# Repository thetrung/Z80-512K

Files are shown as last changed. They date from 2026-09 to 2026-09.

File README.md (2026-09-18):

# Z80-512K 
Z80 system with 512K SRAM/EEPROM & Expansion Bus.

### Note
This one start as independent Z80 system, target at 8Mhz clock & put any I/O into expansion bus instead.

### 3D Preview 
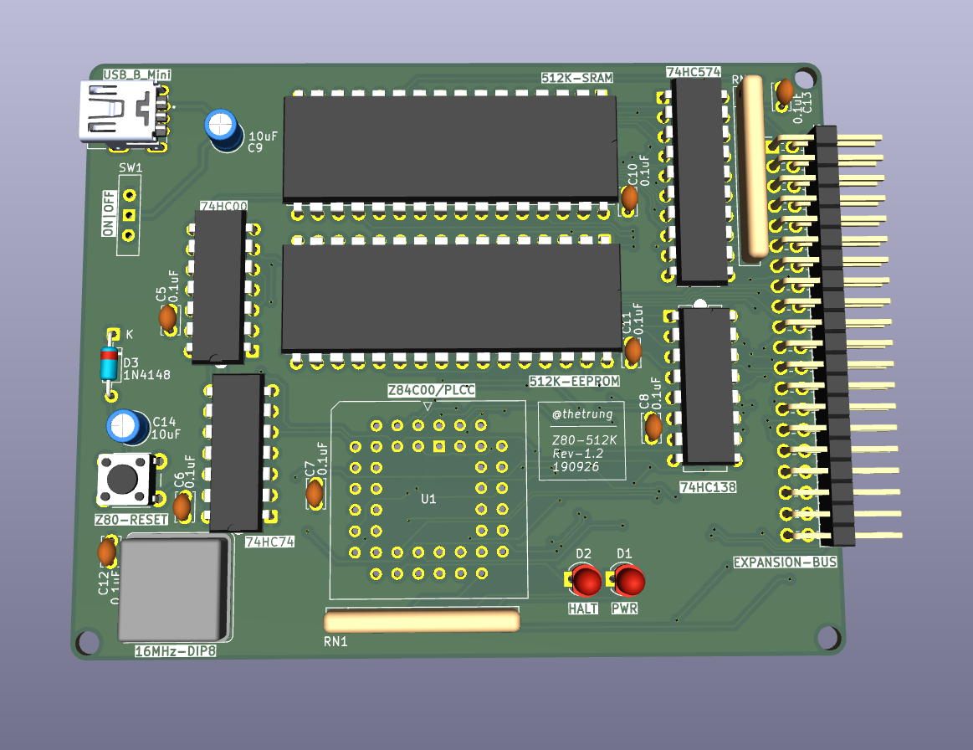
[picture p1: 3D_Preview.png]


### Placement (SilkScreen)
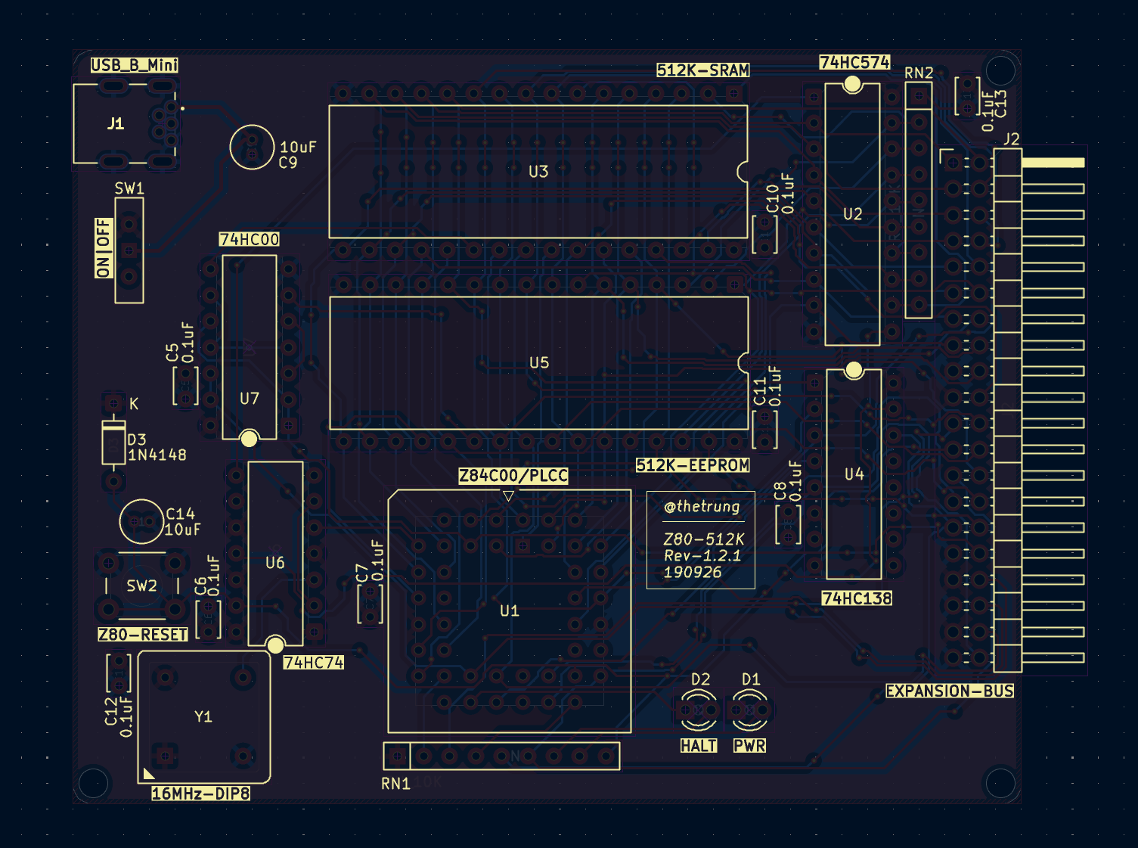
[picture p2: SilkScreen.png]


### Schematic 
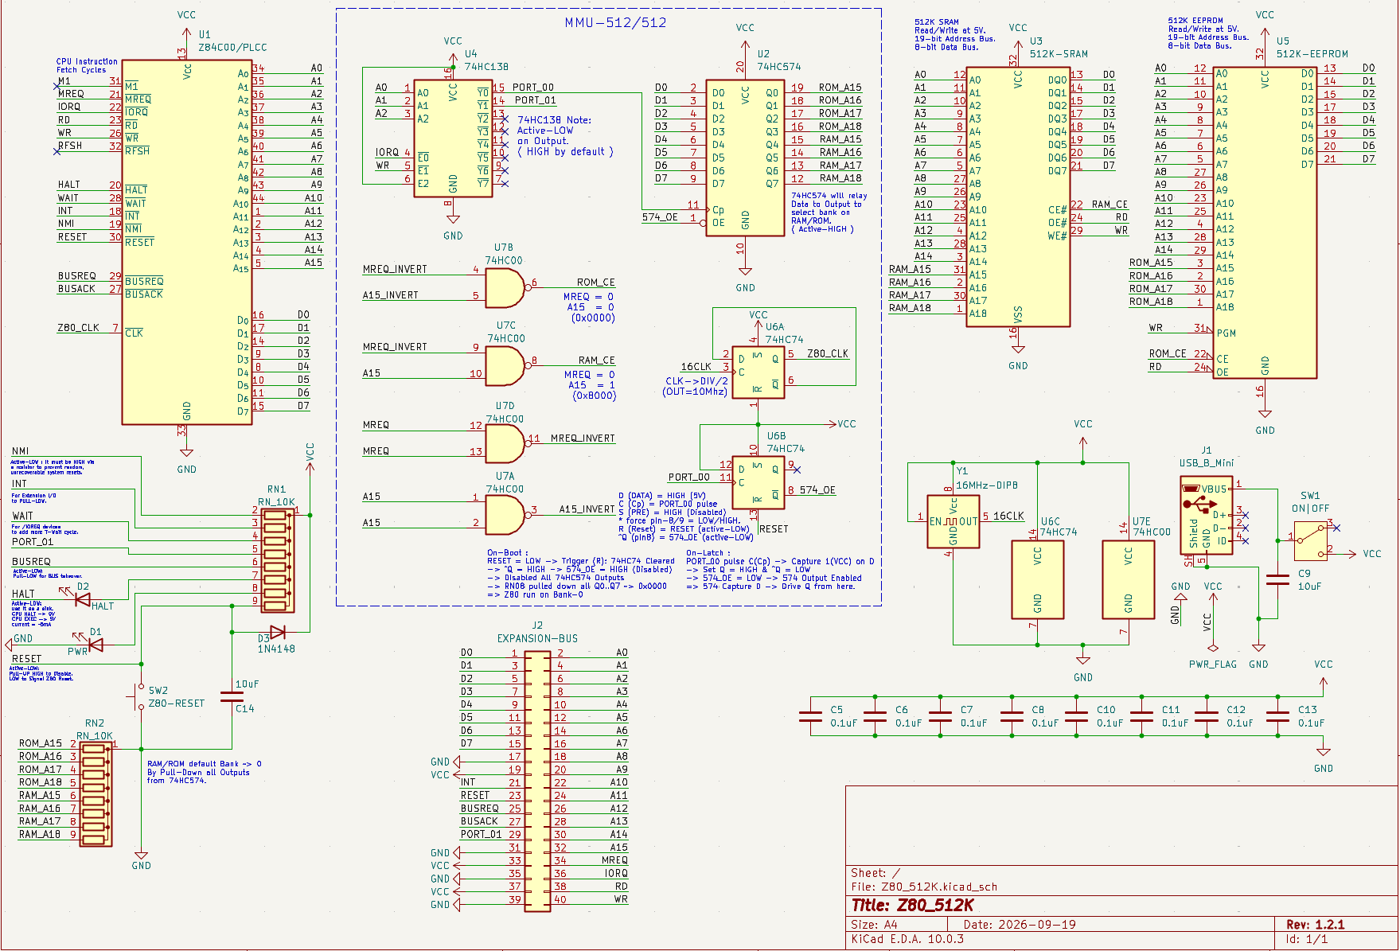
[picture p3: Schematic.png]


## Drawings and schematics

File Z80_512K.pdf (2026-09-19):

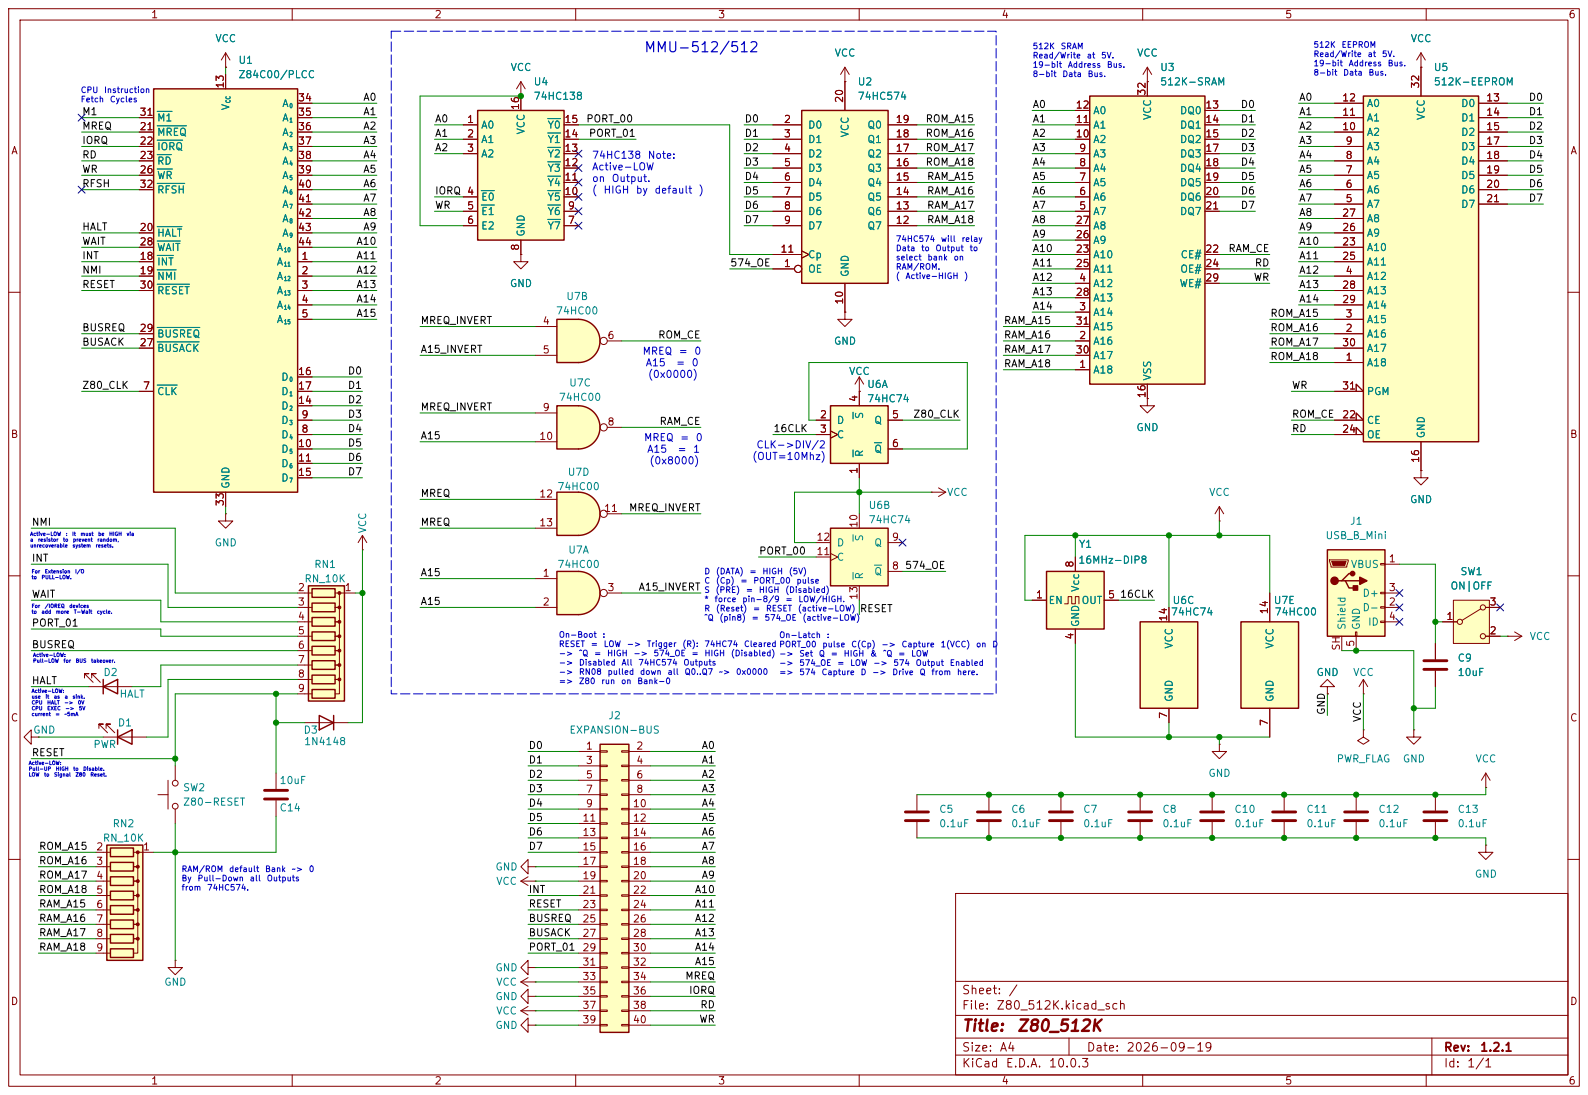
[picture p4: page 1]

VCC
512K SRAM Read/Write at 5V. 19-bit Address Bus. 8-bit Data Bus. U1

INT 18 NMI 19 HALT 20 MREQ 21

512K EEPROM
Read/Write at 5V. 19-bit Address Bus. 8-bit Data Bus.
512K-SRAM VSS 16 VCC 32
GNDVSS 16 VCC 32

Z84C00/PLCC

Active-LOW: Pull-LOW for BUS takeover. For Extension I/O
to PULL-LOW. For /IOREQ devices

Active-LOW: use it as a sink. CPU HALT -> 0V CPU EXEC -> 5V

Active-LOW: Pull-UP HIGH to Disable. LOW to Signal Z80 Reset.

Size: A4 | Rev: 1.2.1
KiCad E.D.A. 10.0.3 | Id: 1/1

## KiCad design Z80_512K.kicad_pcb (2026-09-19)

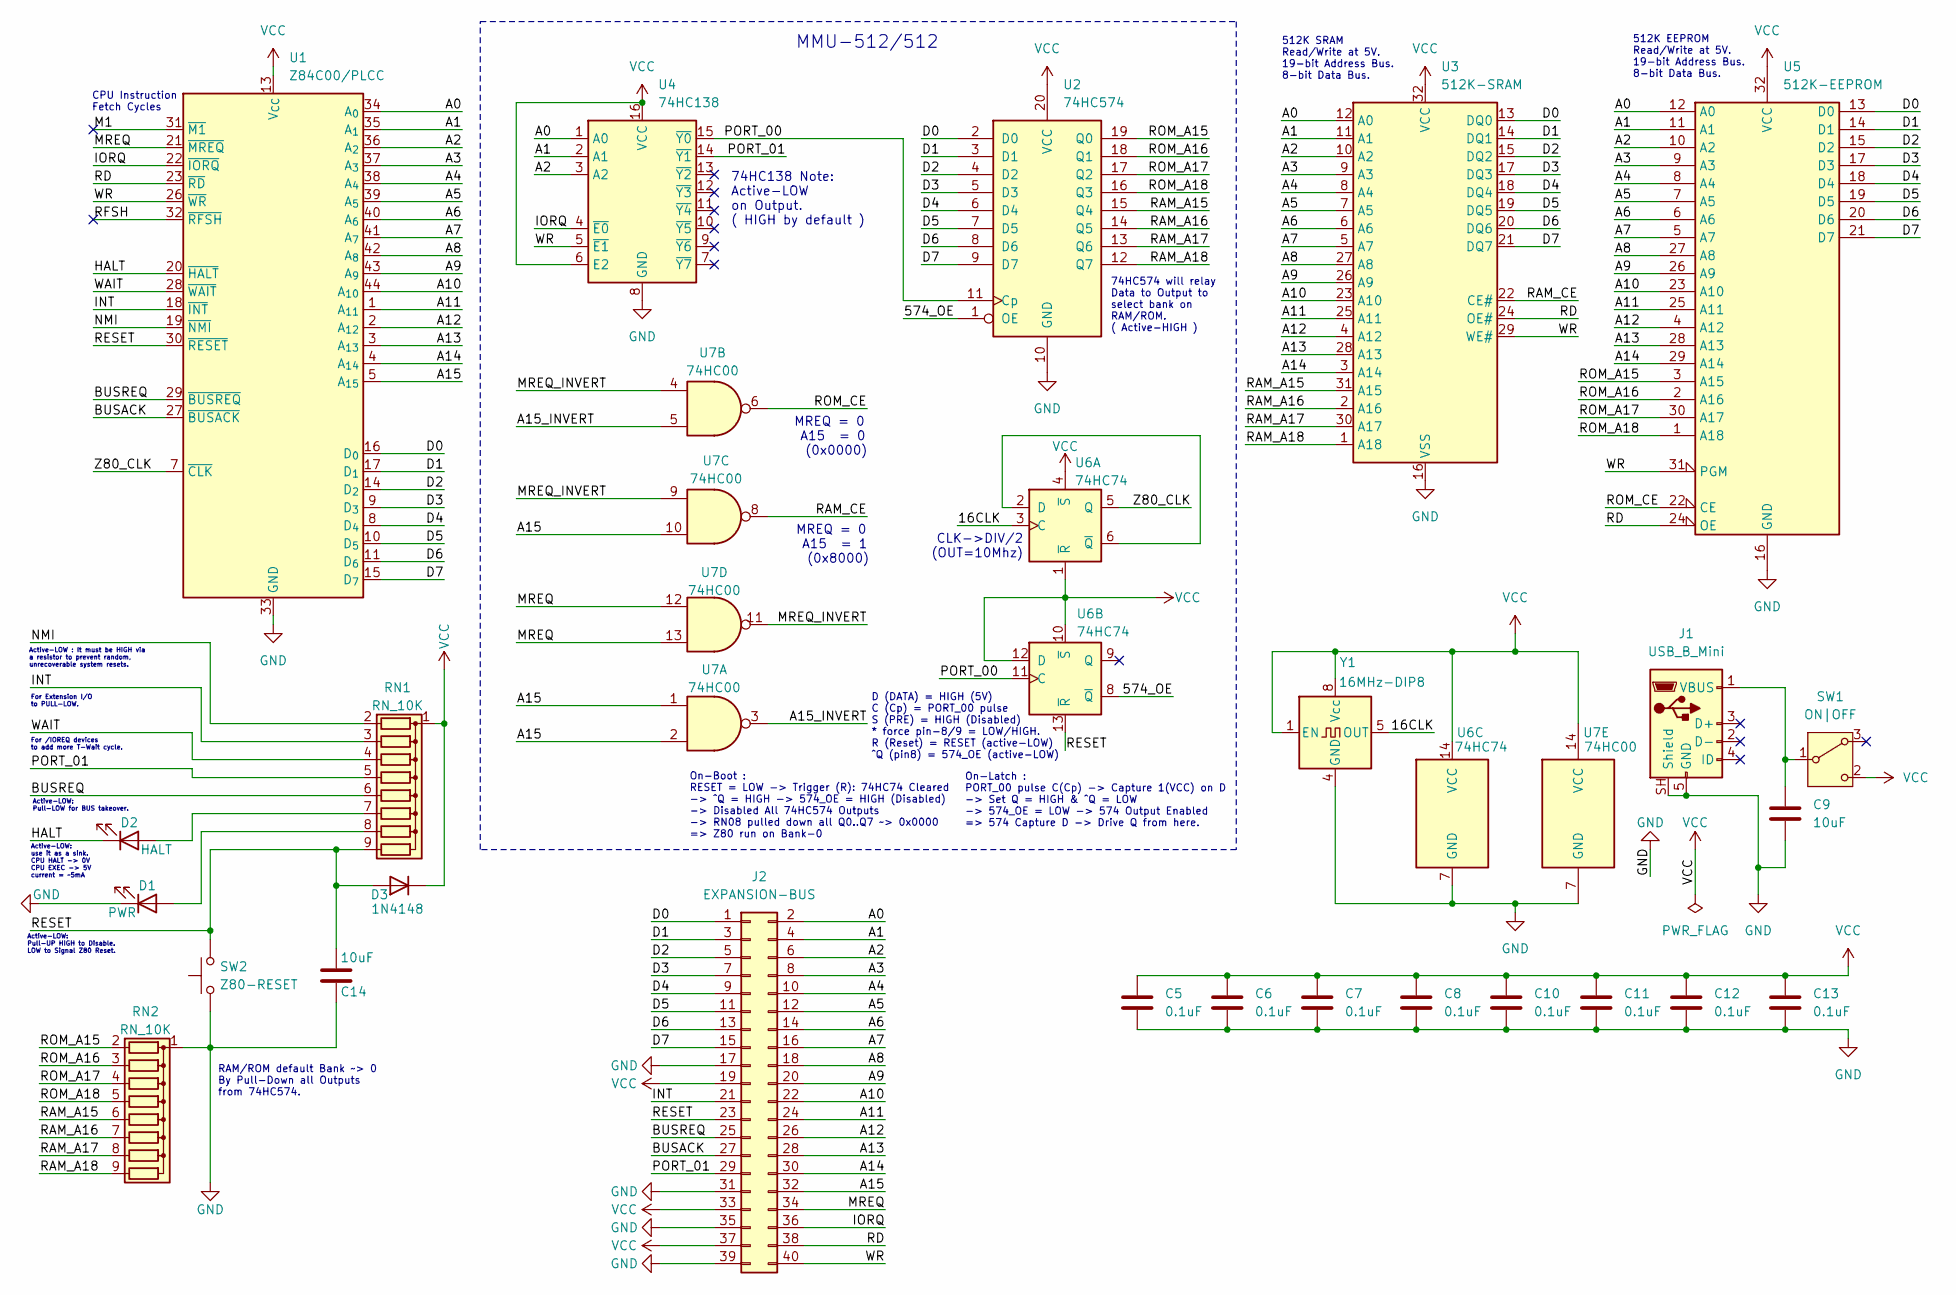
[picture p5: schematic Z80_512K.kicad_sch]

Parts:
C5, C6, C7, C8, C10, C11, C12, C13: 0.1uF; C_Disc_D3.4mm_W2.1mm_P2.50mm
C9, C14: 10uF; C_Radial_D4.0mm_H5.0mm_P1.50mm
D1: PWR; LED_D3.0mm
D2: HALT; LED_D3.0mm
D3: 1N4148; D_DO-35_SOD27_P7.62mm_Horizontal
J1: USB_B_Mini; USB_MINI_B_90_Angled
J2: EXPANSION-BUS; PinHeader_2x20_P2.54mm_Horizontal
RN1, RN2: RN_10K; R_Array_SIP9
SW1: ON|OFF; SW_Slide-03_Wuerth-WS-SLTV_10x2.5x6.4_P2.54mm
SW2: Z80-RESET; SW_PUSH_6mm
U1: Z84C00/PLCC; PLCC-44_THT-Socket
U2: 74HC574; DIP-20_W7.62mm
U3: 512K-SRAM; DIP-32_W15.24mm
U4: 74HC138; DIP-16_W7.62mm
U5: 512K-EEPROM; DIP-32_W15.24mm
U6: 74HC74; DIP-14_W7.62mm
U7: 74HC00; DIP-14_W7.62mm
Y1: 16MHz-DIP8; Oscillator_DIP-8

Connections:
/16CLK: U6.3 (C), Y1.5 (OUT)
/574_OE: U2.1 (OE), U6.8 (~Q)
/A0: J2.2, U1.34 (A_{0}), U3.12 (A0), U4.1 (A0), U5.12 (A0)
/A1: J2.4, U1.35 (A_{1}), U3.11 (A1), U4.2 (A1), U5.11 (A1)
/A2: J2.6, U1.36 (A_{2}), U3.10 (A2), U4.3 (A2), U5.10 (A2)
/A3: J2.8, U1.37 (A_{3}), U3.9 (A3), U5.9 (A3)
/A4: J2.10, U1.38 (A_{4}), U3.8 (A4), U5.8 (A4)
/A5: J2.12, U1.39 (A_{5}), U3.7 (A5), U5.7 (A5)
/A6: J2.14, U1.40 (A_{6}), U3.6 (A6), U5.6 (A6)
/A7: J2.16, U1.41 (A_{7}), U3.5 (A7), U5.5 (A7)
/A8: J2.18, U1.42 (A_{8}), U3.27 (A8), U5.27 (A8)
/A9: J2.20, U1.43 (A_{9}), U3.26 (A9), U5.26 (A9)
/A10: J2.22, U1.44 (A_{10}), U3.23 (A10), U5.23 (A10)
/A11: J2.24, U1.1 (A_{11}), U3.25 (A11), U5.25 (A11)
/A12: J2.26, U1.2 (A_{12}), U3.4 (A12), U5.4 (A12)
/A13: J2.28, U1.3 (A_{13}), U3.28 (A13), U5.28 (A13)
/A14: J2.30, U1.4 (A_{14}), U3.3 (A14), U5.29 (A14)
/A15: J2.32, U1.5 (A_{15}), U7.1, U7.2, U7.10
/A15_INVERT: U7.3, U7.5
/BUSACK: J2.27, U1.27 (~BUSACK)
/BUSREQ: J2.25, RN1.6 (R5), U1.29 (~BUSREQ)
/D0: J2.1, U1.16 (D_{0}), U2.2 (D0), U3.13 (DQ0), U5.13 (D0)
/D1: J2.3, U1.17 (D_{1}), U2.3 (D1), U3.14 (DQ1), U5.14 (D1)
/D2: J2.5, U1.14 (D_{2}), U2.4 (D2), U3.15 (DQ2), U5.15 (D2)
/D3: J2.7, U1.9 (D_{3}), U2.5 (D3), U3.17 (DQ3), U5.17 (D3)
/D4: J2.9, U1.8 (D_{4}), U2.6 (D4), U3.18 (DQ4), U5.18 (D4)
/D5: J2.11, U1.10 (D_{5}), U2.7 (D5), U3.19 (DQ5), U5.19 (D5)
/D6: J2.13, U1.11 (D_{6}), U2.8 (D6), U3.20 (DQ6), U5.20 (D6)
/D7: J2.15, U1.15 (D_{7}), U2.9 (D7), U3.21 (DQ7), U5.21 (D7)
/HALT: D2.1 (K), U1.20 (~HALT)
/INT: J2.21, RN1.3 (R2), U1.18 (~INT)
/IORQ: J2.36, U1.22 (~IORQ), U4.4 (~E0)
/M1: U1.31 (~M1)
/MREQ: J2.34, U1.21 (~MREQ), U7.12, U7.13
/MREQ_INVERT: U7.4, U7.9, U7.11
/NMI: RN1.2 (R1), U1.19 (~NMI)
/PORT_00: U2.11 (Cp), U4.15 (~Y0), U6.11 (C)
/PORT_01: J2.29, RN1.5 (R4), U4.14 (~Y1)
/RAM_A15: RN2.6 (R5), U2.15 (Q4), U3.31 (A15)
/RAM_A16: RN2.7 (R6), U2.14 (Q5), U3.2 (A16)
/RAM_A17: RN2.8 (R7), U2.13 (Q6), U3.30 (A17)
/RAM_A18: RN2.9 (R8), U2.12 (Q7), U3.1 (A18)
/RAM_CE: U3.22 (CE#), U7.8
/RD: J2.38, U1.23 (~RD), U3.24 (OE#), U5.24 (OE)
/RESET: C14.1, D3.2 (A), J2.23, RN1.9 (R8), SW2.2, U1.30 (~RESET), U6.13 (~R)
/RFSH: U1.32 (~RFSH)
/ROM_A15: RN2.2 (R1), U2.19 (Q0), U5.3 (A15)
/ROM_A16: RN2.3 (R2), U2.18 (Q1), U5.2 (A16)
/ROM_A17: RN2.4 (R3), U2.17 (Q2), U5.30 (A17)
/ROM_A18: RN2.5 (R4), U2.16 (Q3), U5.1 (A18)
/ROM_CE: U5.22 (CE), U7.6
/WAIT: RN1.4 (R3), U1.28 (~WAIT)
/WR: J2.40, U1.26 (~WR), U3.29 (WE#), U4.5 (~E1), U5.31 (PGM)
/Z80_CLK: U1.7 (~CLK), U6.5 (Q)
GND: C5.1, C6.1, C7.1, C8.1, C9.1, C10.1, C11.1, C12.1, C13.1, C14.2, D1.1 (K), J1.5 (GND), J1.SH (Shield), J2.17, J2.31, J2.35, J2.39, RN2.1 (common), SW2.1, U1.33 (GND), U2.10 (GND), U3.16 (VSS), U4.8 (GND), U5.16 (GND), U6.7 (GND), U7.7 (GND), Y1.4 (GND)
unnamed: D1.2 (A), RN1.8 (R7)
unnamed: D2.2 (A), RN1.7 (R6)
unnamed: C9.2, J1.1 (VBUS), SW1.1 (B)
unnamed: U6.2 (D), U6.6 (~Q)
VCC: C5.2, C6.2, C7.2, C8.2, C10.2, C11.2, C12.2, C13.2, D3.1 (K), J2.19, J2.33, J2.37, RN1.1 (common), SW1.2 (C), U1.13 (V_{CC}), U2.20 (VCC), U3.32 (VCC), U4.6 (E2), U4.16 (VCC), U5.32 (VCC), U6.1 (~R), U6.4 (~S), U6.10 (~S), U6.12 (D), U6.14 (VCC), U7.14 (VCC), Y1.1 (EN), Y1.8 (Vcc)

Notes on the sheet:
MREQ = 0 A15 = 0 (0x0000)
RAM/ROM default Bank ~> 0 By Pull-Down all Outputs from 74HC574.
For /IOREQ devices to add more T-Wait cycle.
512K SRAM Read/Write at 5V. 19-bit Address Bus. 8-bit Data Bus.
Active-LOW: use it as a sink. CPU HALT -> 0V CPU EXEC -> 5V current = ~5mA
CLK->DIV/2 (OUT=10Mhz)
For Extension I/O to PULL-LOW.
74HC138 Note: Active-LOW on Output. ( HIGH by default )
D (DATA) = HIGH (5V) C (Cp) = PORT_00 pulse S (PRE) = HIGH (Disabled) * force pin-8/9 = LOW/HIGH. R (Reset) = RESET (active-LOW) ^Q (pin8) = 574_OE (active-LOW)
512K EEPROM Read/Write at 5V. 19-bit Address Bus. 8-bit Data Bus.
On-Boot : RESET = LOW -> Trigger (R): 74HC74 Cleared -> ^Q = HIGH -> 574_OE = HIGH (Disabled) -> Disabled All 74HC574 Outputs -> RN08 pulled down all Q0..Q7 ~> 0x0000 => Z80 run on Bank-0
Active-LOW : It must be HIGH via a resistor to prevent random, unrecoverable system resets.
Active-LOW: Pull-UP HIGH to Disable. LOW to Signal Z80 Reset.
On-Latch : PORT_00 pulse C(Cp) -> Capture 1(VCC) on D -> Set Q = HIGH & ^Q = LOW -> 574_OE = LOW -> 574 Output Enabled => 574 Capture D -> Drive Q from here.
74HC574 will relay Data to Output to select bank on RAM/ROM. ( Active-HIGH )
CPU Instruction Fetch Cycles
Active-LOW: Pull-LOW for BUS takeover.
MREQ = 0 A15 = 1 (0x8000)
MMU-512/512

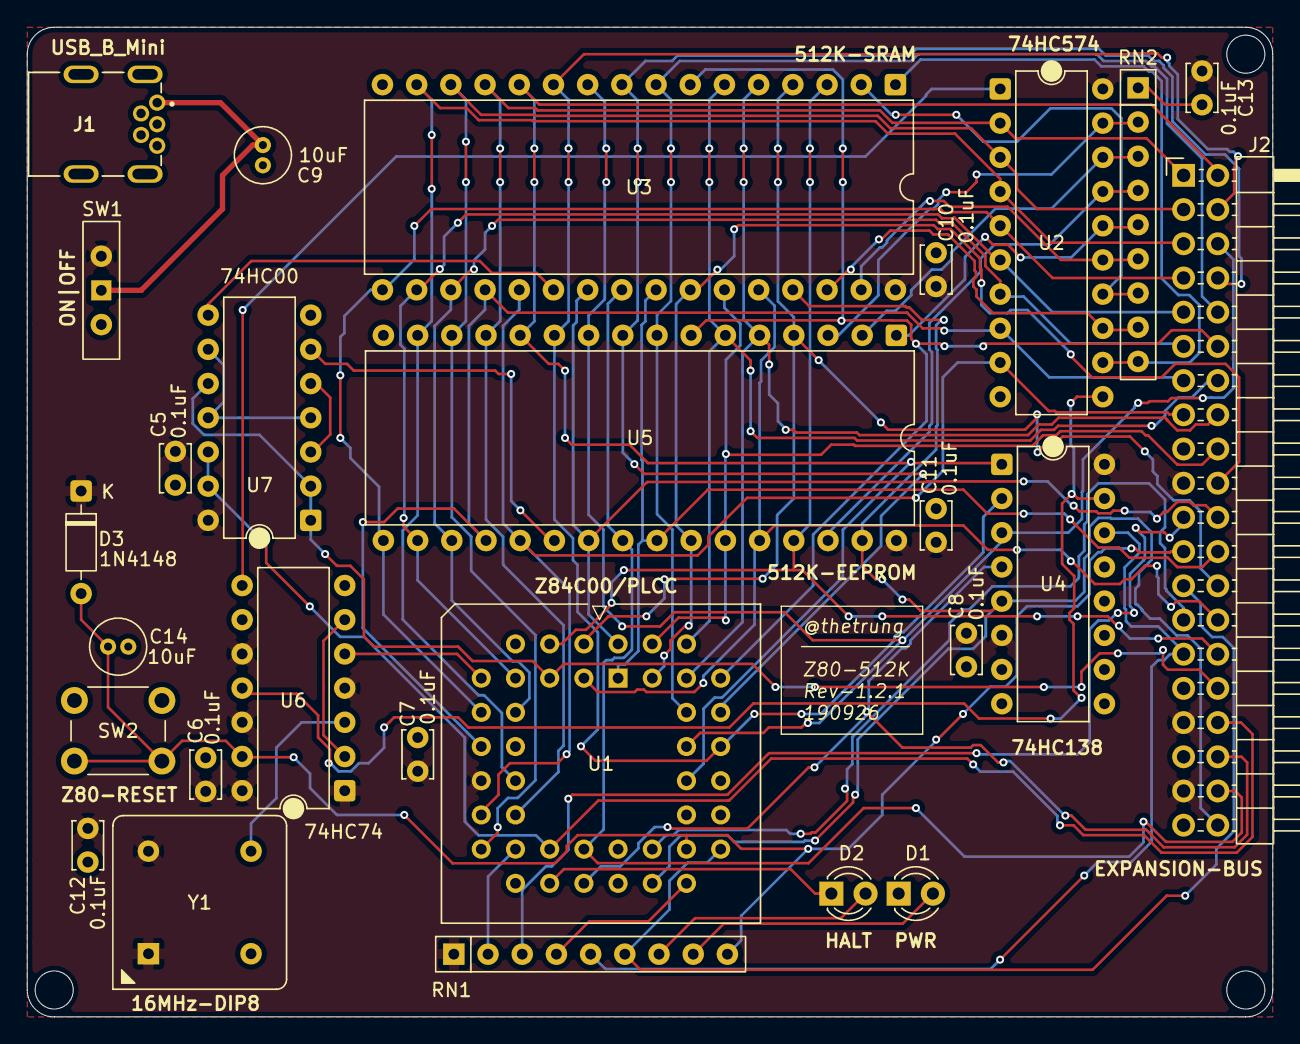
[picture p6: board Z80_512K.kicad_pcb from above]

Board: 2 copper layers, 92.5 x 73.5 mm, 27 parts (0 on the bottom side), 58 nets.

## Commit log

2026-08-27 Init Z80-512K project
    [Z80_512K.kicad_pcb, Z80_512K.kicad_sch]
2026-08-29 Finished Routing Layout.
    [Z80_512K.kicad_pcb, Z80_512K.kicad_sch]
2026-08-29 Plot & FAB-ready.
    [Z80_512K.kicad_pcb]
2026-08-29 RN-A06 ~> RN-A05: remove R-BUSACK
    [Z80_512K.kicad_pcb, Z80_512K.kicad_sch]
2026-08-29 add 3x 1.414mm holes.
    [Z80_512K.kicad_pcb]
2026-08-30 Refine Expansion-Bus: remove all EXs & add VCC/GND rails + Diode/USB.
    [Z80_512K.kicad_pcb, Z80_512K.kicad_sch]
2026-09-18 Rev1.1: fixed 74HC00/74 footprint, schematic(CE,Bus,574..), layout.
    [Z80_512K.kicad_pcb, Z80_512K.kicad_sch]
2026-09-18 Add 1xCap + adjust closer->74HC74.
    [Z80_512K.kicad_pcb, Z80_512K.kicad_sch]
2026-09-18 Rev1.2: Update on Data Latch w/ Flip-Flop
    [Z80_512K.kicad_sch]
2026-09-18 Rev1.2: Fix 74HC574/74 for Bank0.
    [Z80_512K.kicad_pcb, Z80_512K.kicad_sch]
2026-09-19 Rev1.2.1: refine RESET circuit.
    [Z80_512K.kicad_pcb, Z80_512K.kicad_sch]
